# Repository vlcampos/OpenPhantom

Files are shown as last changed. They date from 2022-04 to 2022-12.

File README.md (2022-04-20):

# OpenPhantom
OpenPhantom is an open-source hardware project of a replacement main board for the Gradiente Phantom System model PH-8. The most famous NES clone made in Brazil during the 1980s and early 1990s.
The board was made as a hobby project based on a real board, internet schematics and a lot of reverse engineering.

Some modifications were made to make it easier to reproduce in Brazil and make it a little bit cheaper.
You can check the development progress on my twitter: @vagnerlc.
You are also invited to show any enhancements, modifications and make questions if needed.

You are free to use it in anyway you want: reproduce, sell, mod, etc.

I'm just a hobbyst trying to repair my old consoles and keep the very interesting history of this console alive.

The software used for the schematics was the Kicad 6.0.

Enjoy!

OpenPhantom é um projeto open-source para uma placa de reposição para o Phantom System PH-8 da Gradiente, o mais famoso dos clones de Nintendinho feitos no Brasil nas décadas de 80 e 90.
Essa placa surgiu como um hobby que envolveu uma placa com problemas, esquemas de internet e um bocado de engenharia revera.

Algumas modificações foram feitas para facilitar a reprodução da placa no Brasil.
Se quiserem acompanhar como foi o desenvolvimento é só ver meu twitter @vagnerlc.
Mandem as modificações, melhorias e projetos pessoais lá também e em caso de dúvidas é só me chamar por lá.

Por ser open source vocês podem usar o projeto do jeito que quiserem: venda, reprodução, modificação, etc...

Eu sou só um hobista tentando consertar minhas velharias e manter a história desse console viva.

Para o desenvolvimento foi utilizado o Kicad 6.0.

Divirtam-se!

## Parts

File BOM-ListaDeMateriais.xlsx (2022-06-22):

Bill of Materials/Lista de Materiais OpenPhantom
Referência/Reference | QTD/QTY | Descrição/Description
C1 | 1 | Capacitor Cerâmico/Ceramic Capacitor 22pF
C2, C4, C7, C8, C9, C10, C12, C13, C14, C15, C18, C19, C21 | 13 | Capacitor Cerâmico/Ceramic Capacitor 100nF
C3 | 1 | Capacitor Cerâmico/Ceramic Capacitor 2,2uF 100V
C5, C23, C24 | 3 | Capacitor Cerâmico/Ceramic Capacitor 220pF
C6 | 1 | Capacitor Cerâmico/Ceramic Capacitor 47pF
C11, C17, C22 | 3 | Capacitor Eletrolítico/Electrolytic Capacitor 1uF 100V
C16 | 1 | Capacitor Eletrolítico/Electrolytic Capacitor 4.7uF 16V
C20 | 1 | Capacitor Eletrolítico/Electrolytic Capacitor 100uF 100V
C25 | 1 | Capacitor Eletrolítico/Electrolytic Capacitor 22uF 25V
CV1 | 1 | Capacitor Trimmer (Variável)/Trimmer Cap 30pF
D1 | 1 | LED Vermelho/Red LED
DZ1 | 1 | Diodo Zenner/Zenner Diode 8V2 1W
J1 | 1 | Conector Jack P4 Fêmea
J2 | 1 | Tomada RCA Amarelo/Yellow RCA Jack
J3 | 1 | Tomada RCA Branca/White RCA Jack
JOY1 | 1 | Conector Curto DB9 Macho/Short DB9 Male Connector
JOY2 | 1 | Conector Curto DB9 Macho/Short DB9 Male Connector
Q1 | 2 | Transistor NPN BC548
Q2 | 1 | Transistor BD136
Q3 | 1 | Transistor PNP BC557
R1 | 1 | Resistor 1/4W 1M ohm
R2, R3, R4, R9, R11, R14, R15, R18, R21, R22, R23, R24, R25, R26, R27, R29, R32, R33, R34, R36, R39, R41 | 22 | Resistor 1/4W 10K ohm
R5 | 1 | Resistor 1/4W 150K
R6 | 1 | Resistor 1/4W 560R
R7 | 1 | Resistor 1/4W 680R
R8, R42 | 2 | Resistor 1/4W 1K ohm
R10 | 1 | Resistor 1/4W 220R
R12 | 1 | Resistor 1/4W 330R
R13, R17 | 2 | Resistor 1/4W 100R
R16, R37, R38 | 3 | Resistor 1/4W 150R
R19 | 1 | Resistor 1/4W 22K
R20 | 1 | Resistor 1/4W 12K
R28, R35 | 2 | Resistor 1/4W 220R
R30 | 1 | Resistor 1/4W 47K
R31 | 1 | Resistor 1/4W 2K2
R40 | 1 | Resistor 1/4W 68R
SLOT1 | 1 | Conector 72 Pinos para NES/72 Pin Connector
SW1 | 1 | Chave táctil 6mm/6mm Tactile Switch
SW2 | 1 | Chave táctil 6mm/6mm Tactile Switch
U1 | 1 | CI HM6116 ou UM6116
U2 | 1 | CI HM6116 ou UM6116
U3 | 1 | 74HC04
U4 | 1 | UMC UA6547 CPU
U5 | 1 | CD4013
U6 | 1 | UMC UA6548 PPU
U7 | 1 | 74HC139
U8 | 1 | 74LS373
U9 | 1 | LM7805
U10, U11 | 2 | 74HC368
Y1 | 1 | Cristal/Crystal Oscillator 21.453366 MHz

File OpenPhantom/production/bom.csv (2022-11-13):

Designator | Footprint | Quantity | Value | LCSC Part #
R5 | R_Axial_DIN0207_L6.3mm_D2.5mm_P10.16mm_Horizontal | 1 | 150K
C18 | C_Disc_D4.7mm_W2.5mm_P5.00mm | 1 | 100nF
C22 | CP_Radial_D5.0mm_P2.50mm | 1 | 1uF 100V
C23 | C_Disc_D4.7mm_W2.5mm_P5.00mm | 1 | 220pF
C1 | C_Disc_D4.7mm_W2.5mm_P5.00mm | 1 | 22pF
C16 | CP_Radial_D5.0mm_P2.50mm | 1 | 4.7uF 16V
C21 | C_Disc_D4.7mm_W2.5mm_P5.00mm | 1 | 100nF
C14 | C_Disc_D4.7mm_W2.5mm_P5.00mm | 1 | 100nF
C11 | CP_Radial_D5.0mm_P2.50mm | 1 | 1uF 100V
C3 | CP_Radial_D5.0mm_P2.50mm | 1 | 2,2uF 100V
C17 | CP_Radial_D5.0mm_P2.50mm | 1 | 1uF 100V
C19 | C_Disc_D4.7mm_W2.5mm_P5.00mm | 1 | 100nF
C4 | C_Disc_D4.7mm_W2.5mm_P5.00mm | 1 | 100nF
C7 | C_Disc_D4.7mm_W2.5mm_P5.00mm | 1 | 100nF
C8 | C_Disc_D4.7mm_W2.5mm_P5.00mm | 1 | 100nF
C9 | C_Disc_D4.7mm_W2.5mm_P5.00mm | 1 | 100nF
C12 | C_Disc_D4.7mm_W2.5mm_P5.00mm | 1 | 100nF
J2 | rca_yellow | 1 | Video
C15 | C_Disc_D4.7mm_W2.5mm_P5.00mm | 1 | 100nF
CV1 | TrimmerCap-THT | 1 | 30pF
D1 | LED_D5.0mm | 1 | LED
J1 | BarrelJack_Horizontal | 1 | Barrel_Jack
J3 | rca_white | 1 | Audio
JOY2 | DSUB-9_Male_Horizontal_P2.77x2.84mm_EdgePinOffset7.70mm_Housed_MountingHolesOffset9.12mm | 1 | DB9 Controle 2
Q3 | TO-92_HandSolder | 1 | BC557
Q4 | TO-92_HandSolder | 1 | BC548
Q2 | TO-126-3_Vertical | 1 | BD136
Q1 | TO-92_HandSolder | 1 | BC548
R2 | R_Axial_DIN0207_L6.3mm_D2.5mm_P10.16mm_Horizontal | 1 | 10K
R3 | R_Axial_DIN0207_L6.3mm_D2.5mm_P10.16mm_Horizontal | 1 | 10K
R19 | R_Axial_DIN0207_L6.3mm_D2.5mm_P10.16mm_Horizontal | 1 | 22K
R20 | R_Axial_DIN0207_L6.3mm_D2.5mm_P10.16mm_Horizontal | 1 | 12K
R13 | R_Axial_DIN0207_L6.3mm_D2.5mm_P10.16mm_Horizontal | 1 | 100R
R17 | R_Axial_DIN0207_L6.3mm_D2.5mm_P10.16mm_Horizontal | 1 | 100R
R37 | R_Axial_DIN0207_L6.3mm_D2.5mm_P10.16mm_Horizontal | 1 | 150R
R41 | R_Axial_DIN0207_L6.3mm_D2.5mm_P10.16mm_Horizontal | 1 | 10K
R31 | R_Axial_DIN0207_L6.3mm_D2.5mm_P10.16mm_Horizontal | 1 | 2K2
R28 | R_Axial_DIN0207_L6.3mm_D2.5mm_P10.16mm_Horizontal | 1 | 220R
R40 | R_Axial_DIN0207_L6.3mm_D2.5mm_P10.16mm_Horizontal | 1 | 68R
DZ1 | D_DO-41_SOD81_P10.16mm_Horizontal | 1 | 1N4756A
R27 | R_Axial_DIN0207_L6.3mm_D2.5mm_P10.16mm_Horizontal | 1 | 10K
R29 | R_Axial_DIN0207_L6.3mm_D2.5mm_P10.16mm_Horizontal | 1 | 10K
R33 | R_Axial_DIN0207_L6.3mm_D2.5mm_P10.16mm_Horizontal | 1 | 10K
R36 | R_Axial_DIN0207_L6.3mm_D2.5mm_P10.16mm_Horizontal | 1 | 10K
R39 | R_Axial_DIN0207_L6.3mm_D2.5mm_P10.16mm_Horizontal | 1 | 10K
R11 | R_Axial_DIN0207_L6.3mm_D2.5mm_P10.16mm_Horizontal | 1 | 10K
R12 | R_Axial_DIN0207_L6.3mm_D2.5mm_P10.16mm_Horizontal | 1 | 330R
R7 | R_Axial_DIN0207_L6.3mm_D2.5mm_P10.16mm_Horizontal | 1 | 680R
R4 | R_Axial_DIN0207_L6.3mm_D2.5mm_P10.16mm_Horizontal | 1 | 10K
R6 | R_Axial_DIN0207_L6.3mm_D2.5mm_P10.16mm_Horizontal | 1 | 560R
R8 | R_Axial_DIN0207_L6.3mm_D2.5mm_P10.16mm_Horizontal | 1 | 1K
R9 | R_Axial_DIN0207_L6.3mm_D2.5mm_P10.16mm_Horizontal | 1 | 10K
R10 | R_Axial_DIN0204_L3.6mm_D1.6mm_P7.62mm_Horizontal | 1 | 220R
SLOT1 | Conector_NES_72pinos | 1 | 72-Pin_Connector
U4 | DIP-40_W15.24mm | 1 | UA6547_CPU
U1 | DIP-24_W15.24mm | 1 | UM6116 VRAM
U2 | DIP-24_W15.24mm | 1 | UM6116 WRAM
U8 | DIP-20_W7.62mm | 1 | 74LS373
U7 | DIP-16_W7.62mm | 1 | 74HC139
U11 | DIP-16_W7.62mm | 1 | 74HC368
U3 | DIP-14_W7.62mm | 1 | 74HC04
U5 | DIP-14_W7.62mm | 1 | 4013
U9 | TO-220-3_Vertical | 1 | LM7805_TO220
Y1 | Crystal_HC18-U_Vertical | 1 | 21.453366 MHz
JOY1 | DSUB-9_Male_Horizontal_P2.77x2.84mm_EdgePinOffset7.70mm_Housed_MountingHolesOffset9.12mm | 1 | DB9 Controle 1
R24 | R_Axial_DIN0207_L6.3mm_D2.5mm_P10.16mm_Horizontal | 1 | 10K
R18 | R_Axial_DIN0207_L6.3mm_D2.5mm_P10.16mm_Horizontal | 1 | 10K
R23 | R_Axial_DIN0207_L6.3mm_D2.5mm_P10.16mm_Horizontal | 1 | 10K
R25 | R_Axial_DIN0207_L6.3mm_D2.5mm_P10.16mm_Horizontal | 1 | 10K
R14 | R_Axial_DIN0207_L6.3mm_D2.5mm_P10.16mm_Horizontal | 1 | 10K
R22 | R_Axial_DIN0207_L6.3mm_D2.5mm_P10.16mm_Horizontal | 1 | 10K
R15 | R_Axial_DIN0207_L6.3mm_D2.5mm_P10.16mm_Horizontal | 1 | 10K
R30 | R_Axial_DIN0207_L6.3mm_D2.5mm_P10.16mm_Horizontal | 1 | 47K
C24 | C_Disc_D4.7mm_W2.5mm_P5.00mm | 1 | 220pF
R21 | R_Axial_DIN0207_L6.3mm_D2.5mm_P10.16mm_Horizontal | 1 | 10K
C6 | C_Disc_D4.7mm_W2.5mm_P5.00mm | 1 | 47pF
U10 | DIP-16_W7.62mm | 1 | 74HC368
SW2 | SW_PUSH_6mm | 1 | RESET
R1 | R_Axial_DIN0207_L6.3mm_D2.5mm_P10.16mm_Horizontal | 1 | 1M
R26 | R_Axial_DIN0207_L6.3mm_D2.5mm_P10.16mm_Horizontal | 1 | 10K
U6 | DIP-40_W15.24mm | 1 | UA6548_PPU
C5 | C_Disc_D4.7mm_W2.5mm_P5.00mm | 1 | 220pF
C13 | C_Disc_D4.7mm_W2.5mm_P5.00mm | 1 | 100nF
R32 | R_Axial_DIN0207_L6.3mm_D2.5mm_P10.16mm_Horizontal | 1 | 10K
R34 | R_Axial_DIN0207_L6.3mm_D2.5mm_P10.16mm_Horizontal | 1 | 10K
C2 | C_Disc_D4.7mm_W2.5mm_P5.00mm | 1 | 100nF
SW1 | SW_PUSH_6mm | 1 | POWER
C20 | CP_Radial_D5.0mm_P2.50mm | 1 | 100uF 100V
TP9 | TestPoint_Pad_1.0x1.0mm | 1 | +5V
TP8 | TestPoint_Pad_1.0x1.0mm | 1 | CPU AUDIO 2
TP6 | TestPoint_Pad_1.0x1.0mm | 1 | EXP AUDIO
R35 | R_Axial_DIN0207_L6.3mm_D2.5mm_P10.16mm_Horizontal | 1 | 150R
TP13 | TestPoint_Pad_1.0x1.0mm | 1 | VIDEO OUT
TP5 | TestPoint_Pad_1.0x1.0mm | 1 | +8,2V
TP10 | TestPoint_Pad_1.0x1.0mm | 1 | GND
C10 | C_Disc_D4.7mm_W2.5mm_P5.00mm | 1 | 100nF
TP3 | TestPoint_Pad_1.0x1.0mm | 1 | PPU CLK
TP4 | TestPoint_Pad_1.0x1.0mm | 1 | POWER SUPPLY IN
R16 | R_Axial_DIN0207_L6.3mm_D2.5mm_P10.16mm_Horizontal | 1 | 150R
TP12 | TestPoint_Pad_1.0x1.0mm | 1 | AUDIO OUT
TP1 | TestPoint_Pad_1.0x1.0mm | 1 | CPU CLK
TP11 | TestPoint_Pad_1.0x1.0mm | 1 | PPU CVBS
TP7 | TestPoint_Pad_1.0x1.0mm | 1 | CPU AUDIO 1
TP2 | TestPoint_Pad_1.0x1.0mm | 1 | SYS CLK
C26 | C_Disc_D4.7mm_W2.5mm_P5.00mm | 1 | 150pF

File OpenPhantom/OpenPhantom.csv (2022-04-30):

Source: | C:\Vagner\VagNES\OpenPhantom\OpenPhantom\OpenPhantom.kicad_sch
Date: | 25/04/2022 23:03:25
Tool: | Eeschema (6.0.4)
Generator: | C:\Program Files\KiCad\6.0\bin\scripting\plugins/bom_csv_grouped_by_value_with_fp.py
Component Count: | 107
Ref | Qnty | Value | Cmp name | Footprint | Description | Vendor
C1, | 1 | 22pF | C_Small | Capacitor_THT:C_Disc_D4.7mm_W2.5mm_P5.00mm | Unpolarized capacitor, small symbol
C2, C4, C7, C8, C9, C10, C12, C13, C14, C15, C18, C19, C21, | 13 | 100nF | C_Small | Capacitor_THT:C_Disc_D4.7mm_W2.5mm_P5.00mm | Unpolarized capacitor, small symbol
C3, | 1 | 2,2uF 100V | CP | Capacitor_THT:CP_Radial_D5.0mm_P2.50mm
C5, C23, C24, | 3 | 220pF | C | Capacitor_THT:C_Disc_D4.7mm_W2.5mm_P5.00mm | Unpolarized capacitor
C6, | 1 | 47pF | C_Small | Capacitor_THT:C_Disc_D4.7mm_W2.5mm_P5.00mm | Unpolarized capacitor, small symbol
C11, C17, C22, | 3 | 1uF 100V | CP | Capacitor_THT:CP_Radial_D5.0mm_P2.50mm
C16, | 1 | 4.7uF 16V | CP | Capacitor_THT:CP_Radial_D5.0mm_P2.50mm
C20, | 1 | 100uF 100V | CP | Capacitor_THT:CP_Radial_D5.0mm_P2.50mm
C25, | 1 | 22uF 25V | CP | Capacitor_THT:CP_Radial_D5.0mm_P2.50mm
CV1, | 1 | 30pF | C_Variable | NESRE:TrimmerCap-THT | Variable capacitor
D1, | 1 | LED | LED | LED_THT:LED_D5.0mm | Light emitting diode
DZ1, | 1 | 1N4756A | 1N47xxA | Diode_THT:D_DO-41_SOD81_P10.16mm_Horizontal | 1300mW Silicon planar power Zener diodes, DO-41
J1, | 1 | Barrel_Jack | Barrel_Jack | Connector_BarrelJack:BarrelJack_Horizontal | DC Barrel Jack
J2, | 1 | Video | Conn_Coaxial | Conectores Vagner:rca_yellow | coaxial connector (BNC, SMA, SMB, SMC, Cinch/RCA, LEMO, ...)
J3, | 1 | Audio | Conn_Coaxial | Conectores Vagner:rca_white | coaxial connector (BNC, SMA, SMB, SMC, Cinch/RCA, LEMO, ...)
JOY1, | 1 | DB9 Controle 1 | DB9_Male | Connector_Dsub:DSUB-9_Male_Horizontal_P2.77x2.84mm_EdgePinOffset7.70mm_Housed_MountingHolesOffset9.12mm | 9-pin male D-SUB connector
JOY2, | 1 | DB9 Controle 2 | DB9_Male | Connector_Dsub:DSUB-9_Male_Horizontal_P2.77x2.84mm_EdgePinOffset7.70mm_Housed_MountingHolesOffset9.12mm | 9-pin male D-SUB connector
Q1, Q4, | 2 | BC548 | BC548 | Package_TO_SOT_THT:TO-92_HandSolder | 0.1A Ic, 30V Vce, Small Signal NPN Transistor, TO-92
Q2, | 1 | BD136 | BD136 | Package_TO_SOT_THT:TO-126-3_Vertical | 1.5A Ic, 45V Vce, Low Voltage Transistor, TO-126
Q3, | 1 | BC557 | BC557 | Package_TO_SOT_THT:TO-92_HandSolder | 0.1A Ic, 45V Vce, PNP Small Signal Transistor, TO-92
R1, | 1 | 1M | R_Small | Resistor_THT:R_Axial_DIN0207_L6.3mm_D2.5mm_P10.16mm_Horizontal | Resistor, small symbol
R2, R3, R4, R9, R11, R14, R15, R18, R21, R22, R23, R24, R25, R26, R27, R29, R32, R33, R34, R36, R39, R41, | 22 | 10K | R | Resistor_THT:R_Axial_DIN0207_L6.3mm_D2.5mm_P10.16mm_Horizontal | Resistor
R5, | 1 | 150K | R_Small | Resistor_THT:R_Axial_DIN0207_L6.3mm_D2.5mm_P10.16mm_Horizontal | Resistor, small symbol
R6, | 1 | 560R | R_Small | Resistor_THT:R_Axial_DIN0207_L6.3mm_D2.5mm_P10.16mm_Horizontal | Resistor, small symbol
R7, | 1 | 680R | R_Small | Resistor_THT:R_Axial_DIN0207_L6.3mm_D2.5mm_P10.16mm_Horizontal | Resistor, small symbol
R8, R42, | 2 | 1K | R_Small | Resistor_THT:R_Axial_DIN0207_L6.3mm_D2.5mm_P10.16mm_Horizontal | Resistor, small symbol
R10, | 1 | 220R | R_Small | Resistor_THT:R_Axial_DIN0204_L3.6mm_D1.6mm_P7.62mm_Horizontal | Resistor, small symbol
R12, | 1 | 330R | R_Small | Resistor_THT:R_Axial_DIN0207_L6.3mm_D2.5mm_P10.16mm_Horizontal | Resistor, small symbol
R13, R17, | 2 | 100R | R | Resistor_THT:R_Axial_DIN0207_L6.3mm_D2.5mm_P10.16mm_Horizontal | Resistor
R16, R37, R38, | 3 | 150R | R_Small | Resistor_THT:R_Axial_DIN0207_L6.3mm_D2.5mm_P10.16mm_Horizontal | Resistor, small symbol
R19, | 1 | 22K | R | Resistor_THT:R_Axial_DIN0207_L6.3mm_D2.5mm_P10.16mm_Horizontal | Resistor
R20, | 1 | 12K | R | Resistor_THT:R_Axial_DIN0207_L6.3mm_D2.5mm_P10.16mm_Horizontal | Resistor
R28, R35, | 2 | 220R | R_Small | Resistor_THT:R_Axial_DIN0207_L6.3mm_D2.5mm_P10.16mm_Horizontal | Resistor, small symbol
R30, | 1 | 47K | R | Resistor_THT:R_Axial_DIN0207_L6.3mm_D2.5mm_P10.16mm_Horizontal | Resistor
R31, | 1 | 2K2 | R_Small | Resistor_THT:R_Axial_DIN0207_L6.3mm_D2.5mm_P10.16mm_Horizontal | Resistor, small symbol
R40, | 1 | 68R | R_Small | Resistor_THT:R_Axial_DIN0207_L6.3mm_D2.5mm_P10.16mm_Horizontal | Resistor, small symbol
SLOT1, | 1 | 72-Pin_Connector | 72-Pin_Connector | Conectores Vagner:Conector_NES_72pinos
SW1, | 1 | POWER | SW_Push | Button_Switch_THT:SW_PUSH_6mm | Push button switch, generic, two pins
SW2, | 1 | RESET | SW_Push | Button_Switch_THT:SW_PUSH_6mm | Push button switch, generic, two pins
TP1, | 1 | CPU CLK | TestPoint | TestPoint:TestPoint_Pad_1.0x1.0mm | test point
TP2, | 1 | SYS CLK | TestPoint | TestPoint:TestPoint_Pad_1.0x1.0mm | test point
TP3, | 1 | PPU CLK | TestPoint | TestPoint:TestPoint_Pad_1.0x1.0mm | test point
TP4, | 1 | POWER SUPPLY IN | TestPoint | TestPoint:TestPoint_Pad_1.0x1.0mm | test point
TP5, | 1 | +8,2V | TestPoint | TestPoint:TestPoint_Pad_1.0x1.0mm | test point
TP6, | 1 | EXP AUDIO | TestPoint | TestPoint:TestPoint_Pad_1.0x1.0mm | test point
TP7, | 1 | CPU AUDIO 1 | TestPoint | TestPoint:TestPoint_Pad_1.0x1.0mm | test point
TP8, | 1 | CPU AUDIO 2 | TestPoint | TestPoint:TestPoint_Pad_1.0x1.0mm | test point
TP9, | 1 | +5V | TestPoint | TestPoint:TestPoint_Pad_1.0x1.0mm | test point
TP10, | 1 | GND | TestPoint | TestPoint:TestPoint_Pad_1.0x1.0mm | test point
TP11, | 1 | PPU CVBS | TestPoint | TestPoint:TestPoint_Pad_1.0x1.0mm | test point
TP12, | 1 | AUDIO OUT | TestPoint | TestPoint:TestPoint_Pad_1.0x1.0mm | test point
TP13, | 1 | VIDEO OUT | TestPoint | TestPoint:TestPoint_Pad_1.0x1.0mm | test point
U1, | 1 | UM6116 VRAM | 2KB_SRAM | Package_DIP:DIP-24_W15.24mm
U2, | 1 | UM6116 WRAM | 2KB_SRAM | Package_DIP:DIP-24_W15.24mm
U3, | 1 | 74HC04 | 74HC04 | Package_DIP:DIP-14_W7.62mm | Hex Inverter
U4, | 1 | UA6547_CPU | UA6547_CPU | Package_DIP:DIP-40_W15.24mm | CPU NES - PAL-M
U5, | 1 | 4013 | 4013 | Package_DIP:DIP-14_W7.62mm | Dual D FlipFlop, Set & reset
U6, | 1 | UA6548_PPU | UA6548_PPU | Package_DIP:DIP-40_W15.24mm | PPU NES - PAL-M 60Hz
U7, | 1 | 74HC139 | 74HC139 | Package_DIP:DIP-16_W7.62mm
U8, | 1 | 74LS373 | 74LS373 | Package_DIP:DIP-20_W7.62mm | 8-bit Latch, 3-state outputs
U9, | 1 | LM7805_TO220 | LM7805_TO220 | Package_TO_SOT_THT:TO-220-3_Vertical | Positive 1A 35V Linear Regulator, Fixed Output 5V, TO-220
U10, U11, | 2 | 74HC368 | 74HC368 | Package_DIP:DIP-16_W7.62mm
Y1, | 1 | 21.453366 MHz | Crystal | Crystal:Crystal_HC18-U_Vertical | Two pin crystal

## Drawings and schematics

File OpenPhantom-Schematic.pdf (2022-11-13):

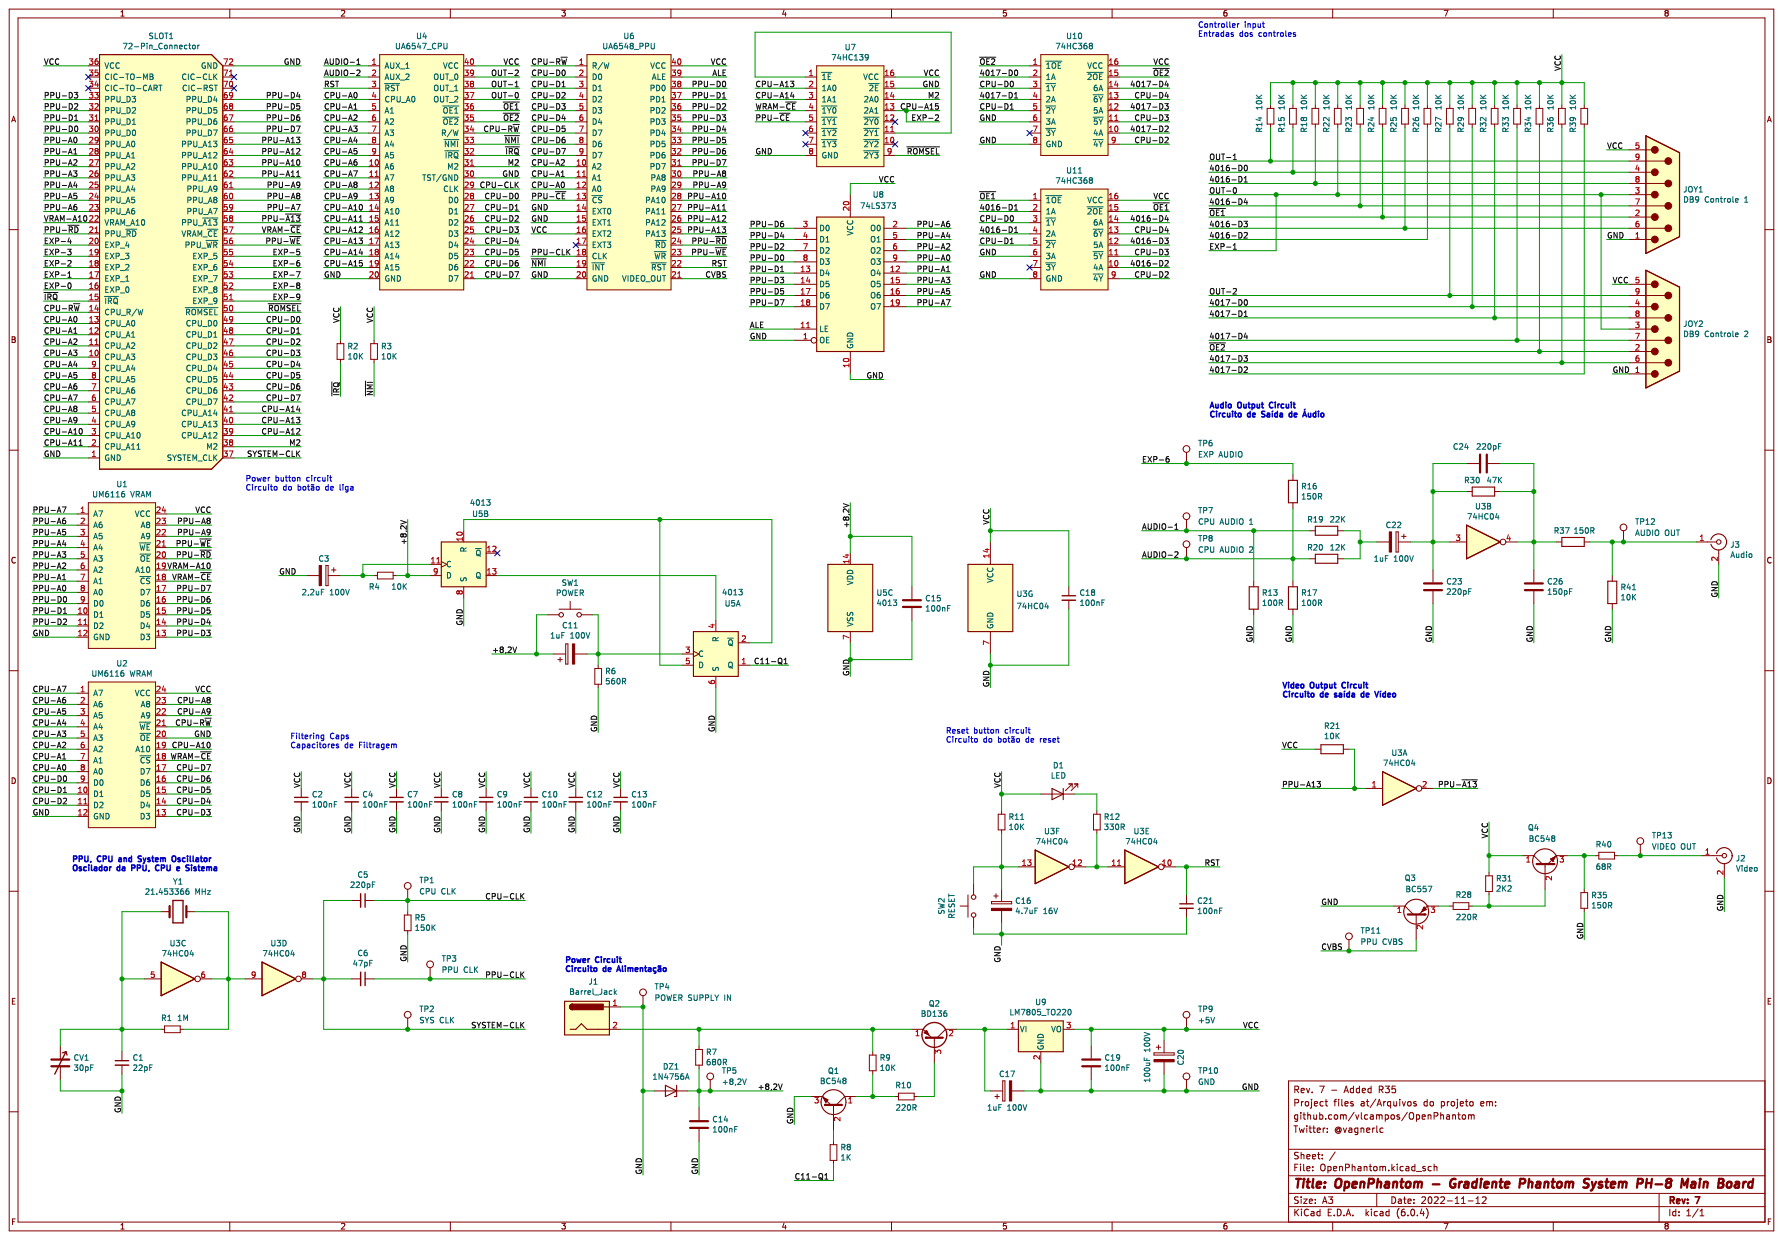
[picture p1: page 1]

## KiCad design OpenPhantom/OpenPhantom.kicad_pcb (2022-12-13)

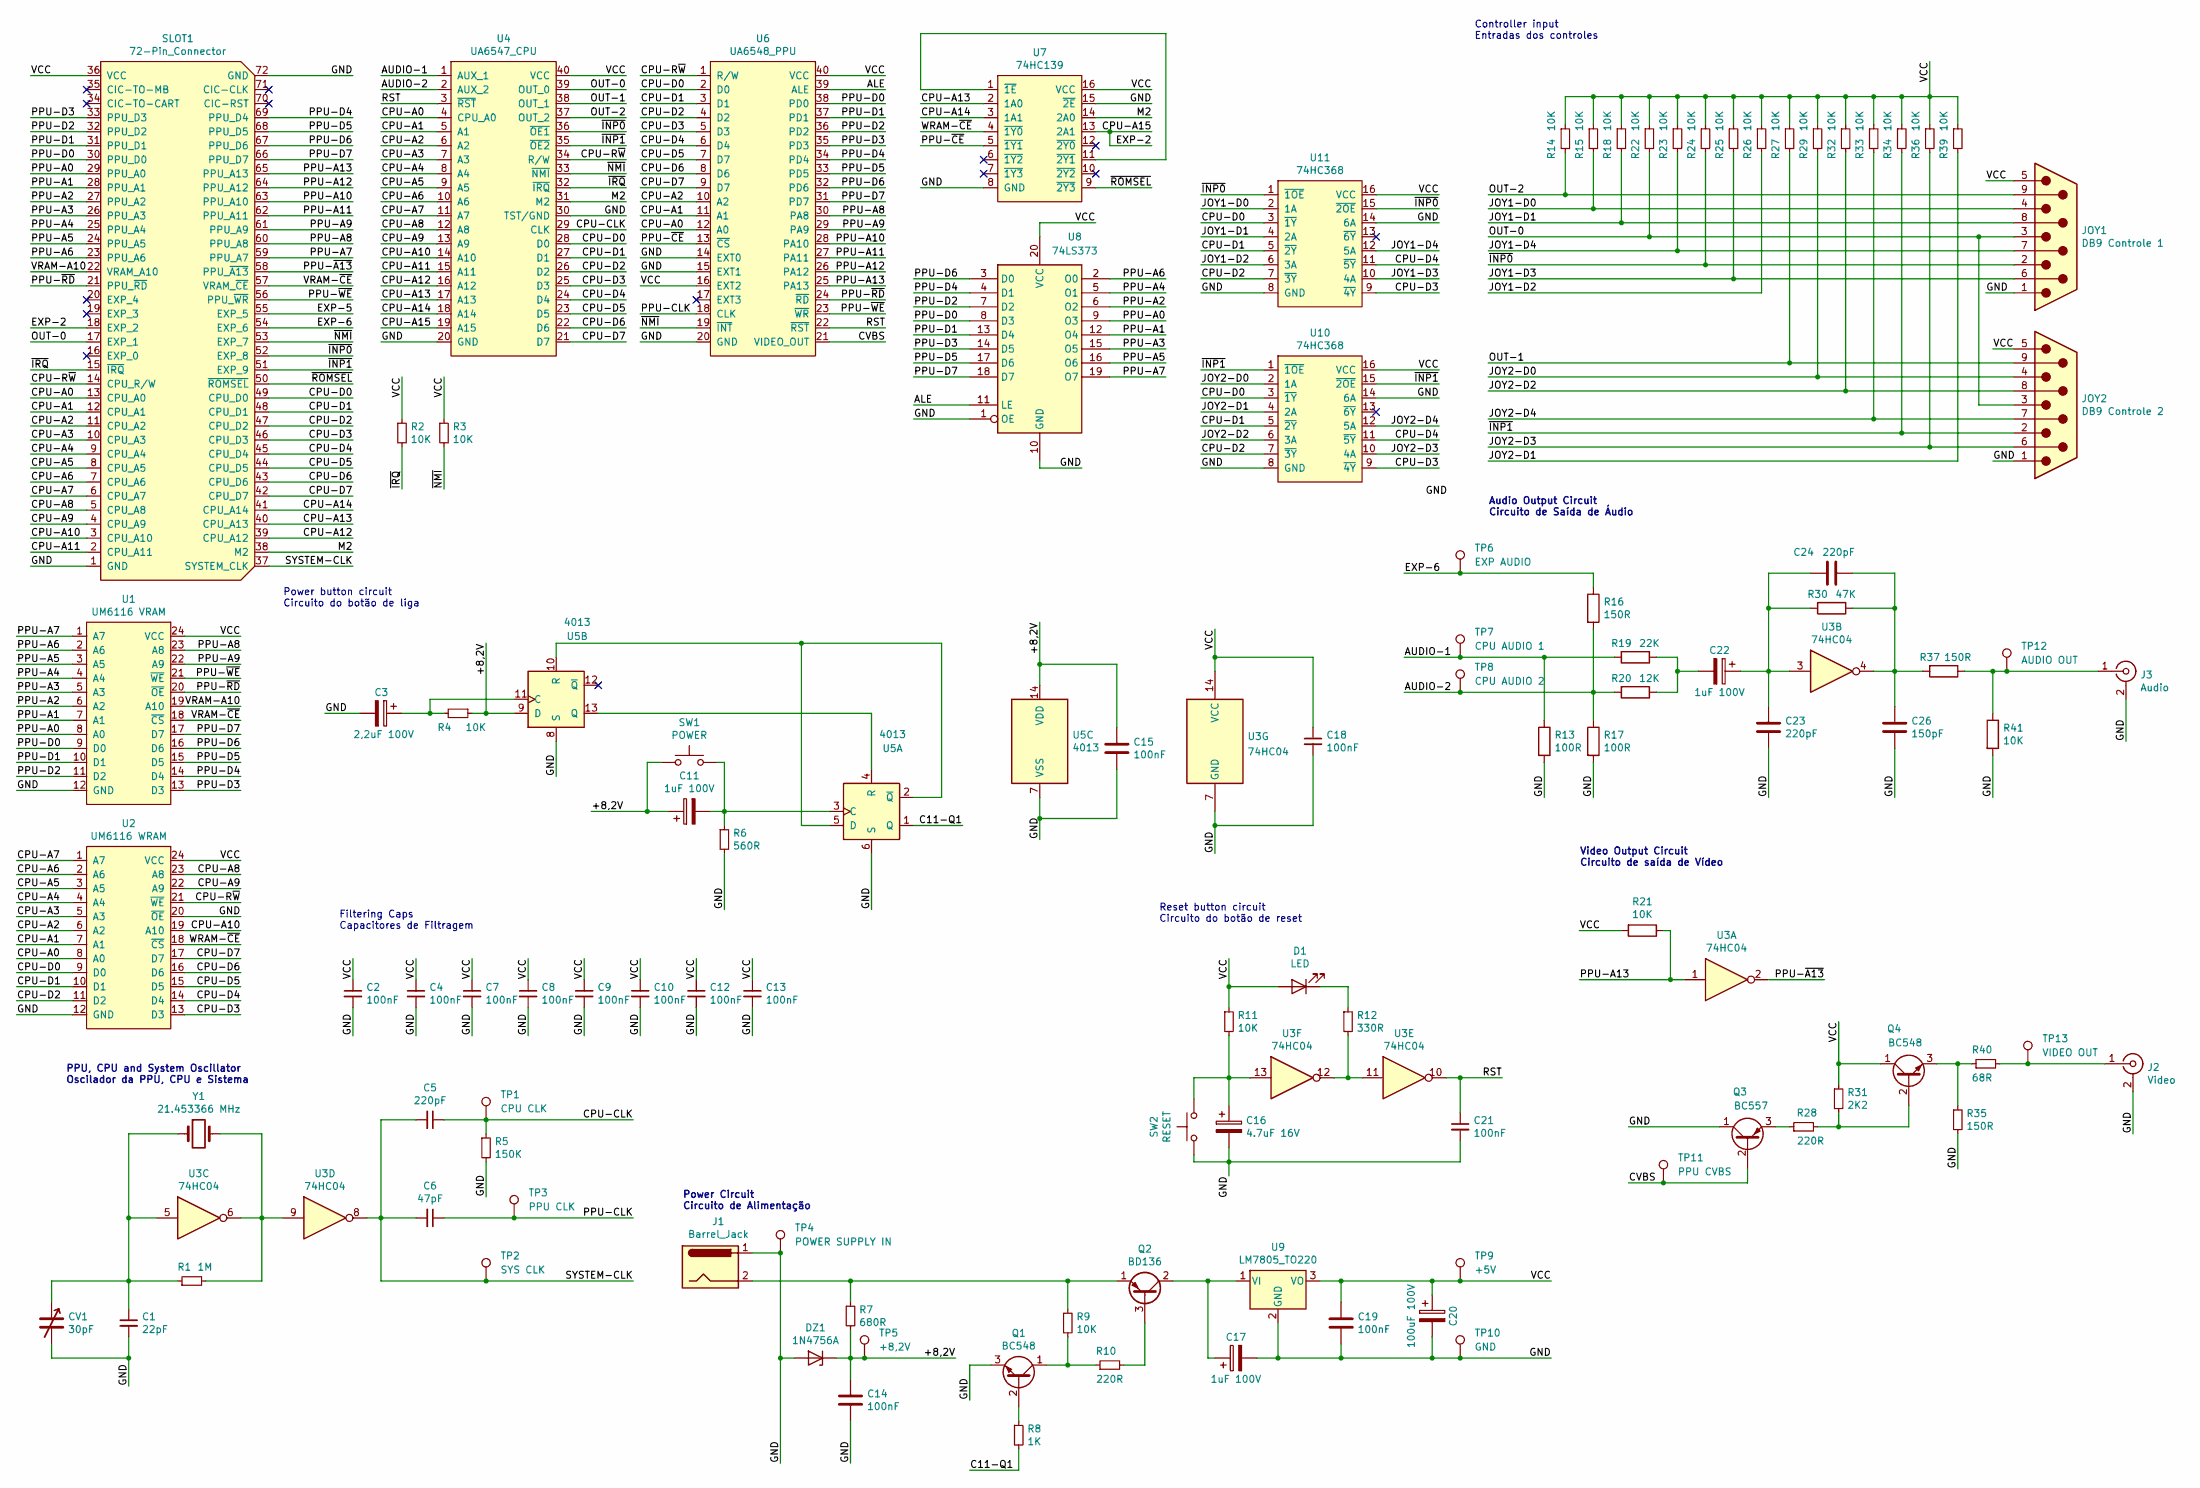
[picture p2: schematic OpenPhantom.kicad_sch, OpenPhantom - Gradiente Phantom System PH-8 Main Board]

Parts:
C1: 22pF; C_Disc_D4.7mm_W2.5mm_P5.00mm
C2, C4, C7, C8, C9, C10, C12, C13, C14, C15, C18, C19, C21: 100nF; C_Disc_D4.7mm_W2.5mm_P5.00mm
C3: 2,2uF 100V; CP_Radial_D5.0mm_P2.50mm
C5, C23, C24: 220pF; C_Disc_D4.7mm_W2.5mm_P5.00mm
C6: 47pF; C_Disc_D4.7mm_W2.5mm_P5.00mm
C11, C17, C22: 1uF 100V; CP_Radial_D5.0mm_P2.50mm
C16: 4.7uF 16V; CP_Radial_D5.0mm_P2.50mm
C20: 100uF 100V; CP_Radial_D5.0mm_P2.50mm
C26: 150pF; C_Disc_D4.7mm_W2.5mm_P5.00mm
CV1: 30pF; TrimmerCap-THT
D1: LED; LED_D5.0mm
DZ1: 1N4756A; D_DO-41_SOD81_P10.16mm_Horizontal
J1: Barrel_Jack; BarrelJack_Horizontal
J2: Video; rca_yellow
J3: Audio; rca_white
JOY1: DB9 Controle 1; DSUB-9_Male_Horizontal_P2.77x2.84mm_EdgePinOffset7.70mm_Hou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
JOY2: DB9 Controle 2; DSUB-9_Male_Horizontal_P2.77x2.84mm_EdgePinOffset7.70mm_Hou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
Q1, Q4: BC548; TO-92_HandSolder
Q2: BD136; TO-126-3_Vertical
Q3: BC557; TO-92_HandSolder
R1: 1M; R_Axial_DIN0207_L6.3mm_D2.5mm_P10.16mm_Horizontal
R2, R3, R4, R9, R11, R14, R15, R18, R21, R22, R23, R24, R25, R26, R27, R29, R32, R33, R34, R36, R39, R41: 10K; R_Axial_DIN0207_L6.3mm_D2.5mm_P10.16mm_Horizontal
R5: 150K; R_Axial_DIN0207_L6.3mm_D2.5mm_P10.16mm_Horizontal
R6: 560R; R_Axial_DIN0207_L6.3mm_D2.5mm_P10.16mm_Horizontal
R7: 680R; R_Axial_DIN0207_L6.3mm_D2.5mm_P10.16mm_Horizontal
R8: 1K; R_Axial_DIN0207_L6.3mm_D2.5mm_P10.16mm_Horizontal
R10: 220R; R_Axial_DIN0204_L3.6mm_D1.6mm_P7.62mm_Horizontal
R12: 330R; R_Axial_DIN0207_L6.3mm_D2.5mm_P10.16mm_Horizontal
R13, R17: 100R; R_Axial_DIN0207_L6.3mm_D2.5mm_P10.16mm_Horizontal
R16, R35, R37: 150R; R_Axial_DIN0207_L6.3mm_D2.5mm_P10.16mm_Horizontal
R19: 22K; R_Axial_DIN0207_L6.3mm_D2.5mm_P10.16mm_Horizontal
R20: 12K; R_Axial_DIN0207_L6.3mm_D2.5mm_P10.16mm_Horizontal
R28: 220R; R_Axial_DIN0207_L6.3mm_D2.5mm_P10.16mm_Horizontal
R30: 47K; R_Axial_DIN0207_L6.3mm_D2.5mm_P10.16mm_Horizontal
R31: 2K2; R_Axial_DIN0207_L6.3mm_D2.5mm_P10.16mm_Horizontal
R40: 68R; R_Axial_DIN0207_L6.3mm_D2.5mm_P10.16mm_Horizontal
SLOT1: 72-Pin_Connector; Conector_NES_72pinos
SW1: POWER; SW_PUSH_6mm
SW2: RESET; SW_PUSH_6mm
TP1: CPU CLK; TestPoint_Pad_1.0x1.0mm
TP2: SYS CLK; TestPoint_Pad_1.0x1.0mm
TP3: PPU CLK; TestPoint_Pad_1.0x1.0mm
TP4: POWER SUPPLY IN; TestPoint_Pad_1.0x1.0mm
TP5: +8,2V; TestPoint_Pad_1.0x1.0mm
TP6: EXP AUDIO; TestPoint_Pad_1.0x1.0mm
TP7: CPU AUDIO 1; TestPoint_Pad_1.0x1.0mm
TP8: CPU AUDIO 2; TestPoint_Pad_1.0x1.0mm
TP9: +5V; TestPoint_Pad_1.0x1.0mm
TP10: GND; TestPoint_Pad_1.0x1.0mm
TP11: PPU CVBS; TestPoint_Pad_1.0x1.0mm
TP12: AUDIO OUT; TestPoint_Pad_1.0x1.0mm
TP13: VIDEO OUT; TestPoint_Pad_1.0x1.0mm
U1: UM6116 VRAM; DIP-24_W15.24mm
U2: UM6116 WRAM; DIP-24_W15.24mm
U3: 74HC04; DIP-14_W7.62mm
U4: UA6547_CPU; DIP-40_W15.24mm
U5: 4013; DIP-14_W7.62mm
U6: UA6548_PPU; DIP-40_W15.24mm
U7: 74HC139; DIP-16_W7.62mm
U8: 74LS373; DIP-20_W7.62mm
U9: LM7805_TO220; TO-220-3_Vertical
U10, U11: 74HC368; DIP-16_W7.62mm
Y1: 21.453366 MHz; Crystal_HC18-U_Vertical

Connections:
/+8,2V: C11.1, C14.1, C15.1, DZ1.1 (K), R4.1, R7.2, SW1.1, TP5.1, U5.9 (D), U5.14 (VDD)
/ALE: U6.39 (ALE), U8.11 (LE)
/AUDIO-1: R13.1, R19.2, TP7.1, U4.1 (AUX_1)
/AUDIO-2: R16.2, R17.1, R20.2, TP8.1, U4.2 (AUX_2)
/C11-Q1: R8.2, U5.1 (Q)
/CPU-A0: SLOT1.13 (CPU_A0), U2.8 (A0), U4.4 (CPU_A0), U6.12 (A0)
/CPU-A1: SLOT1.12 (CPU_A1), U2.7 (A1), U4.5 (A1), U6.11 (A1)
/CPU-A2: SLOT1.11 (CPU_A2), U2.6 (A2), U4.6 (A2), U6.10 (A2)
/CPU-A3: SLOT1.10 (CPU_A3), U2.5 (A3~), U4.7 (A3)
/CPU-A4: SLOT1.9 (CPU_A4), U2.4 (A4~), U4.8 (A4)
/CPU-A5: SLOT1.8 (CPU_A5), U2.3 (A5~), U4.9 (A5)
/CPU-A6: SLOT1.7 (CPU_A6), U2.2 (A6~), U4.10 (A6)
/CPU-A7: SLOT1.6 (CPU_A7), U2.1 (A7), U4.11 (A7)
/CPU-A8: SLOT1.5 (CPU_A8), U2.23 (A8), U4.12 (A8)
/CPU-A9: SLOT1.4 (CPU_A9), U2.22 (A9), U4.13 (A9)
/CPU-A10: SLOT1.3 (CPU_A10), U2.19 (A10), U4.14 (A10)
/CPU-A11: SLOT1.2 (CPU_A11), U4.15 (A11)
/CPU-A12: SLOT1.39 (CPU_A12), U4.16 (A12)
/CPU-A13: SLOT1.40 (CPU_A13), U4.17 (A13), U7.2 (1A0)
/CPU-A14: SLOT1.41 (CPU_A14), U4.18 (A14), U7.3 (1A1)
/CPU-A15: SLOT1.18 (EXP_2), U4.19 (A15), U7.13 (2A1)
/CPU-CLK: C5.1, R5.1, TP1.1, U4.29 (CLK)
/CPU-D0: SLOT1.49 (CPU_D0), U2.9 (D0), U4.28 (D0), U6.2 (D0), U10.3 (~1Y), U11.3 (~1Y)
/CPU-D1: SLOT1.48 (CPU_D1), U2.10 (D1), U4.27 (D1), U6.3 (D1), U10.5 (~2Y), U11.5 (~2Y)
/CPU-D2: SLOT1.47 (CPU_D2), U2.11 (D2), U4.26 (D2), U6.4 (D2), U10.7 (~3Y), U11.7 (~3Y)
/CPU-D3: SLOT1.46 (CPU_D3), U2.13 (D3), U4.25 (D3), U6.5 (D3), U10.9 (~4Y), U11.9 (~4Y)
/CPU-D4: SLOT1.45 (CPU_D4), U2.14 (D4), U4.24 (D4), U6.6 (D4), U10.11 (~5Y), U11.11 (~5Y)
/CPU-D5: SLOT1.44 (CPU_D5), U2.15 (D5), U4.23 (D5), U6.7 (D7)
/CPU-D6: SLOT1.43 (CPU_D6), U2.16 (D6), U4.22 (D6), U6.8 (D6)
/CPU-D7: SLOT1.42 (CPU_D7), U2.17 (D7), U4.21 (D7), U6.9 (D7)
/CPU-R~W: SLOT1.14 (CPU_R/W), U2.21 (~WE), U4.34 (R/W), U6.1 (R/W)
/CVBS: Q3.2 (B), TP11.1, U6.21 (VIDEO_OUT)
/EXP-5: SLOT1.55 (EXP_5)
/EXP-6: R16.1, SLOT1.54 (EXP_6), TP6.1
/GND: C1.2, C2.2, C3.2, C4.2, C7.2, C8.2, C9.2, C10.2, C12.2, C13.2, C14.2, C15.2, C16.2, C17.2, C18.2, C19.2, C20.2, C21.2, C23.2, C26.2, CV1.2, DZ1.2 (A), J1.1, J2.2 (Ext), J3.2 (Ext), JOY1.1, JOY2.1, Q1.3 (E), Q3.1 (C), R5.2, R6.2, R13.2, R17.2, R35.2, R41.2, SLOT1.1 (GND), SLOT1.72 (GND), SW2.1, TP4.1, TP10.1, U1.12 (GND~), U2.12 (GND~), U2.20 (~OE), U3.7 (GND), U4.20 (GND), U4.30 (TST/GND), U5.6 (S), U5.7 (VSS), U5.8 (S), U6.14 (EXT0), U6.15 (EXT1), U6.20 (GND), U7.8 (GND), U7.15 (~2E), U8.1 (OE), U8.10 (GND), U9.2 (GND), U10.8 (GND), U10.14 (6A), U11.8 (GND), U11.14 (6A)
/JOY1-D0: JOY1.4, R15.2, U11.2 (1A)
/JOY1-D1: JOY1.8, R18.2, U11.4 (2A)
/JOY1-D2: R26.2, U11.6 (3A)
/JOY1-D3: JOY1.6, R25.2, U11.10 (4A)
/JOY1-D4: JOY1.7, R23.2, U11.12 (5A)
/JOY2-D0: JOY2.4, R29.2, U10.2 (1A)
/JOY2-D1: R39.2, U10.4 (2A)
/JOY2-D2: JOY2.8, R32.2, U10.6 (3A)
/JOY2-D3: JOY2.6, R36.2, U10.10 (4A)
/JOY2-D4: JOY2.7, R33.2, U10.12 (5A)
/M2: SLOT1.38 (M2), U4.31 (M2), U7.14 (2A0)
/OUT-0: JOY1.3, JOY2.3, R22.2, SLOT1.17 (EXP_1), U4.39 (OUT_0)
/OUT-1: JOY2.9, R27.2, U4.38 (OUT_1)
/OUT-2: JOY1.9, R14.2, U4.37 (OUT_2)
/PPU-A0: SLOT1.29 (PPU_A0), U1.8 (A0), U8.9 (O3)
/PPU-A1: SLOT1.28 (PPU_A1), U1.7 (A1), U8.12 (O4)
/PPU-A2: SLOT1.27 (PPU_A2), U1.6 (A2), U8.6 (O2)
/PPU-A3: SLOT1.26 (PPU_A3), U1.5 (A3~), U8.15 (O5)
/PPU-A4: SLOT1.25 (PPU_A4), U1.4 (A4~), U8.5 (O1)
/PPU-A5: SLOT1.24 (PPU_A5), U1.3 (A5~), U8.16 (O6)
/PPU-A6: SLOT1.23 (PPU_A6), U1.2 (A6~), U8.2 (O0)
/PPU-A7: SLOT1.59 (PPU_A7), U1.1 (A7), U8.19 (O7)
/PPU-A8: SLOT1.60 (PPU_A8), U1.23 (A8), U6.30 (PA8)
/PPU-A9: SLOT1.61 (PPU_A9), U1.22 (A9), U6.29 (PA9)
/PPU-A10: SLOT1.63 (PPU_A10), U6.28 (PA10)
/PPU-A11: SLOT1.62 (PPU_A11), U6.27 (PA11)
/PPU-A12: SLOT1.64 (PPU_A12), U6.26 (PA12)
/PPU-A13: R21.1, SLOT1.65 (PPU_A13), U3.1, U6.25 (PA13)
/PPU-CLK: C6.1, TP3.1, U6.18 (CLK)
/PPU-D0: SLOT1.30 (PPU_D0), U1.9 (D0), U6.38 (PD0), U8.8 (D3)
/PPU-D1: SLOT1.31 (PPU_D1), U1.10 (D1), U6.37 (PD1), U8.13 (D4)
/PPU-D2: SLOT1.32 (PPU_D2), U1.11 (D2), U6.36 (PD2), U8.7 (D2)
/PPU-D3: SLOT1.33 (PPU_D3), U1.13 (D3), U6.35 (PD3), U8.14 (D5)
/PPU-D4: SLOT1.69 (PPU_D4), U1.14 (D4), U6.34 (PD4), U8.4 (D1)
/PPU-D5: SLOT1.68 (PPU_D5), U1.15 (D5), U6.33 (PD5), U8.17 (D6)
/PPU-D6: SLOT1.67 (PPU_D6), U1.16 (D6), U6.32 (PD6), U8.3 (D0)
/PPU-D7: SLOT1.66 (PPU_D7), U1.17 (D7), U6.31 (PD7), U8.18 (D7)
/PPU-~A13: SLOT1.58 (PPU_~A13), U3.2
/PPU-~CE: U6.13 (~CS), U7.5 (~1Y1)
/PPU-~RD: SLOT1.21 (PPU_~RD), U1.20 (~OE), U6.24 (~RD)
/PPU-~WE: SLOT1.56 (PPU_~WR), U1.21 (~WE), U6.23 (~WR)
/RST: C21.1, U3.10, U4.3 (~RST), U6.22 (~RST)
/SYSTEM-CLK: C5.2, C6.2, SLOT1.37 (SYSTEM_CLK), TP2.1, U3.8
/VCC: C2.1, C4.1, C7.1, C8.1, C9.1, C10.1, C12.1, C13.1, C18.1, C19.1, C20.1, D1.2 (A), JOY1.5, JOY2.5, Q4.1 (C), R2.1, R3.1, R11.1, R14.1, R15.1, R18.1, R21.2, R22.1, R23.1, R24.1, R25.1, R26.1, R27.1, R29.1, R31.1, R32.1, R33.1, R34.1, R36.1, R39.1, SLOT1.36 (VCC), TP9.1, U1.24 (VCC), U2.24 (VCC), U3.14 (VCC), U4.40 (VCC), U6.16 (EXT2), U6.40 (VCC), U7.16 (VCC), U8.20 (VCC), U9.3 (VO), U10.16 (VCC), U11.16 (VCC)
/VRAM-A10: SLOT1.22 (VRAM_A10), U1.19 (A10)
/VRAM-~CE: SLOT1.57 (VRAM_~CE), U1.18 (~CS)
/WRAM-~CE: U2.18 (~CS), U7.4 (~1Y0)
/~INP0: JOY1.2, R24.2, SLOT1.52 (EXP_8), U4.36 (~OE1), U11.1 (~1OE), U11.15 (~2OE)
/~INP1: JOY2.2, R34.2, SLOT1.51 (EXP_9), U4.35 (~OE2), U10.1 (~1OE), U10.15 (~2OE)
/~IRQ: R2.2, SLOT1.15 (~IRQ), U4.32 (~IRQ)
/~NMI: R3.2, SLOT1.53 (EXP_7), U4.33 (~NMI), U6.19 (~INT)
/~ROMSEL: SLOT1.50 (~ROMSEL), U7.9 (~2Y3)
unnamed: C1.1, CV1.1, R1.1, U3.5, Y1.1
unnamed: C3.1, R4.2, U5.11 (C)
unnamed: C11.2, R6.1, SW1.2, U5.3 (C)
unnamed: C16.1, R11.2, SW2.2, U3.13
unnamed: C17.1, Q2.2 (C), U9.1 (VI)
unnamed: C22.1, C23.1, C24.2, R30.2, U3.3
unnamed: C22.2, R19.1, R20.1
unnamed: C24.1, C26.1, R30.1, R37.2, U3.4
unnamed: D1.1 (K), R12.1
unnamed: J1.2, Q2.1 (E), R7.1, R9.1
unnamed: J2.1 (In), R40.2, TP13.1
unnamed: J3.1 (In), R37.1, R41.1, TP12.1
unnamed: Q1.1 (C), R9.2, R10.1
unnamed: Q1.2 (B), R8.1
unnamed: Q2.3 (B), R10.2
unnamed: Q3.3 (E), R28.1
unnamed: Q4.2 (B), R28.2, R31.2
unnamed: Q4.3 (E), R35.1, R40.1
unnamed: R1.2, U3.6, U3.9, Y1.2
unnamed: R12.2, U3.11, U3.12
unnamed: U5.2 (~Q), U5.5 (D), U5.10 (R)
unnamed: U5.4 (R), U5.13 (Q)
unnamed: U7.1 (~1E), U7.11 (~2Y1)

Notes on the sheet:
PPU, CPU and System Oscillator Oscilador da PPU, CPU e Sistema
Audio Output Circuit Circuito de Saída de Áudio
Controller input Entradas dos controles
Power button circuit Circuito do botão de liga
Power Circuit Circuito de Alimentação
Video Output Circuit Circuito de saída de Vídeo
Reset button circuit Circuito do botão de reset
Filtering Caps Capacitores de Filtragem

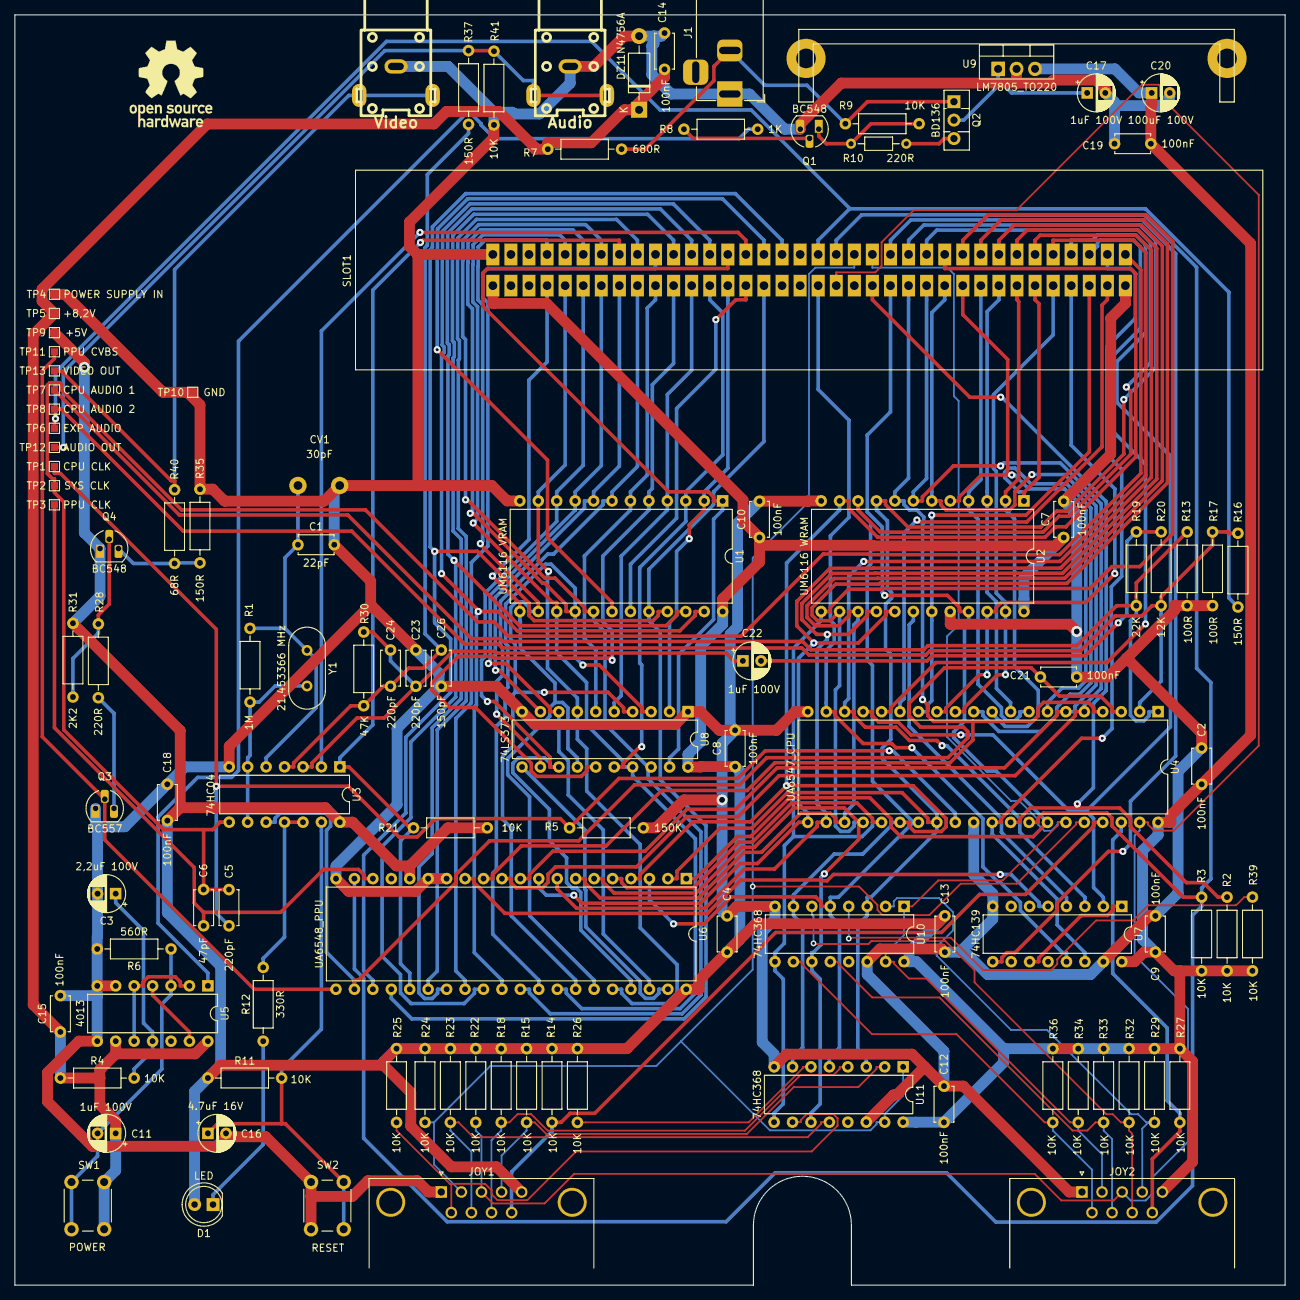
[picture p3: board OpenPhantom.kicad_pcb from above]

Board: 2 copper layers, 175.0 x 175.0 mm, 107 parts (0 on the bottom side), 109 nets.

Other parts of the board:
PT1, PT2: MountingHole_2.7mm_M2.5_Pad

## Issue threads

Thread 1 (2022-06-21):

ola campos

darleiv, 2022-06-21:
voce nao tem um esboço dele em eagle ou dip trace ? queria fazer umas melhorias mas no kikad nao tenho suporte

darleiv, 2022-06-22:
@vlcampos beleza vou tentar fazer um port apartir do seu pdf. notei que tu boto no 74373a D0 D1... dos dois lados como nao consigo abrir o arquivo nao sei se é so uma marcaçaõ pois o 74373 mapeia a PPU pra gerar os ANDRES 1 ao 7
eu to tentando criar um console mas tive problemas de clock e posição de pelas olhe o meu esquema https://ibb.co/h1GjFmD provavel os erro ser por posição da ppu cpu na placa ja analisei o turbo e phamtom e eles posicionaram a ppu cpu estrategicamente pra captar os 2 clock .

darleiv, 2022-06-22:
eu uso o win7 kikad 5 aqui entao nao tenho win10

vlcampos, 2022-06-22:
Agradeço pelo detalhe @darleiv ! Os pinos realmente precisam ser corrigidos, o PPU usa o D0 a D7 também como endereço (ADDRESS) e usa o 373 pra fazer o Latch. Por algum motivo o desenho está diferente da revisão que é funcional. Pelo que você informou e pelo esquemático do seu projeto o problema me parece estar no circuito que você chamou de Pal-M/NTSC. Percebi que ele, que é o circuito gerador do clock base, é diferente do que está no NES e no próprio Phantom. Faltam alguns componentes, como o resistor de 1M ohm em paralelo com cristal oscilador e também percebi que você não usou nem o 74LS04 ou 74HC04.

darleiv, 2022-06-24:
sim sim usei outro clock, eu ate criei uma protoboard improvisada com o clock do phamtom e funcionou perfeito. se voce puder gerar a gerber e postar na git agradeço pois meu kikad nao abre a versao 6 - o clock que usei esta no FC japa por isso é diferente.
aqui tem umas fotos da placa que fiz https://www.facebook.com/italian2024/posts/pfbid0KgDwxVPxLSRU1Zy8w8CfLrHYVCaN41Am8LYN1WnCz9fzwUr4kFsQN9wxynoNAdo2l.

darleiv, 2022-06-24:
@vlcampos

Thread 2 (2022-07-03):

fix no sch

darleiv, 2022-07-03:
achei um erro no exp6 tu ligo na entrada do som ele fica na saida

vlcampos, 2022-07-03:
Esse circuito de expansão de áudio não foi testado pois ainda não tenho um jogo com essa capacidade. Ficou assim pq é como está na placa original.

darleiv, 2022-07-04:
estranho no esquema do neto ele é diferente fica na saida , vou ver no meu phamtom onde ta esse sinal ,

darleiv, 2022-07-04:
no nes one CPU sim ele fica na entrada. ja no FC e phamtom ele fica apos o out antes do resistor de 150k de som na saida. https://www.neto-games.com.br/esquemas/neto_esquema_gradiente_phantom_system_ph-8.png - se caso exista phamtom do mesmo modelo com essa divergencia isso comprova uma copia do nes one cpu americano kkk .

darleiv, 2022-07-04:
https://drive.google.com/file/d/16FZqArkm5hY-vEsSpqo13sZnrnWqUEk6/view?usp=sharing

vlcampos, 2022-07-05:
Pode seguir esse circuito do OpenTendo. É garantido que o áudio vai funcionar. O que eu fiz é só uma cópia do Phantom original que até onde eu sei não veio com a expansão de áudio. Ele não tem pq foi feito para os cartuchos americanos que não tem circuitos de expansão de áudio pois o NES original não possui também. Só alguns cartuchos japoneses e o Famicom disk system quem tem esses Chips de áudio expandido. Eu nem esquentei a cabeça com expansão de áudio pq os jogos bons que tem ou everdrive um são caríssimos.

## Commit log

2022-04-19 Board files
    First upload
    [OpenPhantom.kicad_pcb, OpenPhantom.kicad_sch, OpenPhantom.sch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]
2022-04-20 PDF + PCB Routing + `Placement
    Corrected component position. Added PCB Schematic PDF. Changed the logo. Moved the RCA connectors 2mm closer to the PCB edge.
    [OpenPhantom.kicad_pcb, OpenPhantom.kicad_sch]
2022-04-30 New BOM + Schematic
    Updated Bill of Materials and Schematics
    [BOM-ListaDeMateriais.xlsx, OpenPhantom.csv, OpenPhantom.kicad_sch]
2022-05-01 BOM Update
    [BOM-ListaDeMateriais.xlsx]
2022-05-26 Updated track and vias width
    After some comments of other people that used the board, I remade the routing using a wider ground track. The other tracks were made wider too.
    [OpenPhantom.kicad_pcb]
2022-06-22 74LS373 PPU AD Pins FIX
    Fixed 74LS373 pins connected to the AD Pins from PPU (PPU D0 to D7)
    [BOM-ListaDeMateriais.xlsx, OpenPhantom.kicad_pcb, OpenPhantom.kicad_sch]
2022-08-01 Fixed Routes
    Power route fix.
    [OpenPhantom.kicad_pcb, OpenPhantom.kicad_sch]
2022-08-02 RCA Plug fix
    Fixed RCA plug pinout
    [OpenPhantom.kicad_pcb]
2022-10-27 Added C26 + RF circuit removed
    Added C26 removed RF circuit components fixing audio noise.
    [OpenPhantom.kicad_pcb, OpenPhantom.kicad_sch]
2022-11-13 Added R35
    Added R35 to improved image quality.
    [OpenPhantom.kicad_pcb, OpenPhantom.kicad_sch, bom.csv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]
2022-11-13 Fixed PDF Schematic
2022-12-12 Player controller fixed
    [OpenPhantom.kicad_pcb, OpenPhantom.kicad_sch]
2022-12-13 Joy port fix.
    [OpenPhantom.kicad_pcb, OpenPhantom.kicad_sch]
